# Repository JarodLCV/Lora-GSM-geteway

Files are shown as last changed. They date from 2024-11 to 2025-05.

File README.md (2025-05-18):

# **Passerelle LoRa-GSM**  

Un projet combinant des connaissances en électronique et en programmation pour créer un pont entre le GSM et le LoRa.



----

**Table de matières**
- [**Passerelle LoRa-GSM**](#passerelle-lora-gsm)
  - [ℹ️ **Contexte du projet**](#ℹ️-contexte-du-projet)
  - [🗂️ Dossiers](#️-dossiers)
  - [**Réalisation du projet**](#réalisation-du-projet)
    - [**Définitions :**](#définitions-)
  - [Comment continuer le projet](#comment-continuer-le-projet)
  - [Explication du code](#explication-du-code)

----

## ℹ️ **Contexte du projet**

Il s'agit d'un projet du cours de Projet d'Électronique, encadré par Monsieur Christian Peter (<Christian.PETER@univ-cotedazur.fr>), dans le cadre du cursus d'Ingénierie Électronique et Informatique Industrielle de la Polytech de Sophia Antipolis.  
Ce projet consiste à concevoir une ruche connectée, incluant la collecte de données, la transmission de ces données à distance, l’élimination des parasites par laser, etc.  
Cette partie du projet concerne la communication à distance des données et est réalisée par le groupe composé de:
**Guilherme VENTAPANE RODRIGUES** <guilherme@ventapane.eu>
et
**Jarod LECOEUVRE** <jarod.lecoeuvre@etu.univ-cotedazur.fr>

## 🗂️ Dossiers

- 📁 **Compte-rendu** : Les étapes d'avancement du projet et les tâches que chaque membre du groupe avait effectuées.

- 📁 **Partie_Electronique** : Fichiers liés à la partie électronique du projet, tels que le schéma de la carte, la documentation des composants, etc.
  - 📁 **BOM** : Bill of Material de notre projet. La liste des composants nécessaires avec leurs valeurs, pour être placés sur le PCB.
  - 📁 **Documentation_composants** : Fichiers de documentation pour certains composants utilisés dans le projet.
  - 📁 **Eagle_Components** : Composants supplémentaires pour le logiciel EAGLE, qui n'étaient pas présents par défaut et que nous avons dû télécharger pour compléter notre projet.
  - 📁 **Eagle_Schemas** : Schémas que nous avons utilisés pour notre projet, réalisés avec le logiciel EAGLE d'Autodesk.
  - 📁 **Nano to micro simcard adapter 3d** : Un adaptateur de carte SIM vers micro SIM que nous avons imprimé en 3D pour notre projet.
  - 📁 **Anciens_Schemas** : Fichiers de schémas du groupe de l'année dernière.

- 📁 **Partie_Informatique** : Le dossier où se trouve le code qui tourne sur la carte.
  - 📁 **code_groupe_annee_derniere** : Code du projet du groupe de l'année dernière.
  - 📁 **src** : Les fichiers sources de notre projet, où se trouve le fichier main.ino, le fichier principal de notre projet.

## **Réalisation du projet**  

Pour assurer la communication des données sur de longues distances, une passerelle entre LoRa et GSM sera utilisée.  
Cette passerelle sera réalisée à partir d'un circuit imprimé conçu par nous, ainsi que d'un code exécuté sur un **ESP32** connecté à un **SIM7000G**.

Nous nous basons sur le projet de la promotion précédente, réalisé par **Oumar Sadjo Barry & Mor Dieng** / [oumarsadjo / RucherLoRa](https://github.com/oumarsadjo/RucherLoRa)  
<oumar-sadjo.barry@etu.univ-cotedazur.fr> & <mor.dieng@etu.univ-cotedazur.fr>

### **Définitions :**  

**GSM (Global System for Mobile Communications) :**  
C'est un standard de communication mobile utilisé pour la téléphonie cellulaire et la transmission de données. Il permet l’envoi de messages SMS, les appels et la connexion à Internet via **GPRS/EDGE/3G/4G**. Le GSM est largement utilisé pour les dispositifs IoT nécessitant une connectivité dans des environnements sans Wi-Fi.  

**LoRa (Long Range) :**  
C'est une technologie de communication sans fil à longue portée et à faible consommation d'énergie, utilisée pour connecter des dispositifs IoT aux réseaux LPWAN (**Low Power Wide Area Network**). LoRa permet de transmettre de petits paquets de données sur de longues distances (jusqu'à 15 km en zones rurales) avec une consommation d’énergie minimale.  

**ESP32 :**  
C'est un microcontrôleur développé par Espressif, intégrant **Wi-Fi et Bluetooth**, ainsi que plusieurs broches **GPIO** pour les capteurs et modules externes. Il est largement utilisé dans les projets IoT grâce à sa connectivité, sa puissance et son faible coût.  

**SIM7000 :**  
C'est un module de communication **GSM/GPRS/NB-IoT/LTE Cat-M1** développé par Simcom. Il permet aux dispositifs IoT d'envoyer et de recevoir des données via les réseaux mobiles, en prenant en charge les connexions **basse consommation**, idéales pour les capteurs distants et les applications de surveillance.  



## Comment continuer le projet

Il reste encore à :
- [ ] Finaliser le débogage de la carte pour établir une communication stable entre les composants ;
- [ ] Intégrer la partie LoRa ;
- [ ] Optimiser la consommation énergétique de la passerelle, pour un usage autonome sur batterie.

## Explication du code

La bibliothèque utilise la communication série (UART) pour envoyer des commandes AT au module GSM. En interne, elle structure ces commandes de façon organisée, permettant au développeur de simplement appeler des fonctions comme modem.gprsConnect() ou modem.sendSMS(), au lieu d’écrire manuellement des lignes du type `AT+CGDCONT=1`,"IP","internet".

TinyGSM est également optimisée pour fonctionner sur des cartes à faible mémoire (d’où le “Tiny” dans son nom), ce qui la rend efficace même sur des microcontrôleurs limités comme l’Arduino Uno.

Analyse du code et explication des parties principales

Le code de notre projet est organisé en plusieurs étapes : configuration, initialisation du modem, choix des modes réseau, test de la connexion GPRS, et envoi de SMS. Voici un résumé des parties essentielles :

Définition du modem et configuration initiale
Au début du code, on définit le type de modem utilisé :

``` CPP
#define TINY_GSM_MODEM_SIM7000
#define TINY_GSM_RX_BUFFER 1024
#define SerialAT Serial1
```

Ces lignes informent la bibliothèque qu’on utilise un SIM7000. On augmente aussi la taille du buffer de réception à 1024 octets, ce qui est utile pour traiter des réponses longues du modem.

Il y a aussi l’option suivante :

``` CPP
#define DUMP_AT_COMMANDS
```

Cela permet d’afficher toutes les commandes AT envoyées et les réponses reçues. C’est très utile pour déboguer si quelque chose ne fonctionne pas comme prévu.

Paramètres pour le réseau mobile

``` CPP
const char apn[]  = "sl2sfr";
const char gprsUser[] = "";
const char gprsPass[] = "";
```

Ici, on entre les informations nécessaires pour se connecter au réseau mobile. L’APN dépend de l’opérateur utilisé. Dans notre cas, c’est “sl2sfr” car nous utilisons un SIM de SFR.

Initialisation du modem

Dans la fonction setup(), on initialise la communication série avec le modem :

``` CPP
SerialAT.begin(UART_BAUD, SERIAL_8N1, PIN_RX, PIN_TX);
```

Ensuite, on redémarre le modem avec `modem.restart()` et on vérifie si tout s’est bien passé.

On récupère aussi quelques infos utiles :

``` CPP
String name = modem.getModemName();
String modemInfo = modem.getModemInfo();
```

Cela permet d’afficher le nom du modem et quelques infos techniques pour s’assurer que le module est bien reconnu.

Configuration du mode réseau

Dans la `loop()`, on configure le mode de fonctionnement du modem :

``` CPP
modem.sendAT("+CFUN=0"); // désactive le modem temporairement
modem.setNetworkMode(2); // mode automatique
modem.setPreferredMode(1); // priorité au mode CAT-M
modem.sendAT("+CFUN=1"); // réactive le modem
```

Ces commandes AT permettent de choisir comment le modem va chercher le réseau (LTE, GSM, NB-IoT, etc.).

Connexion GPRS

Une fois le modem prêt, on tente de se connecter au réseau mobile :

``` CPP
modem.gprsConnect(apn, gprsUser, gprsPass);
```

Après la connexion, on peut vérifier le signal, l’opérateur, l’IMEI, l’adresse IP locale, etc.

Envoi de SMS

À la fin du code, il y a une partie pour tester l’envoi de SMS :

``` CPP
modem.sendSMS(SMS_TARGET, String("Hello from ") + imei);
```

C’est un test simple qui envoie un message contenant l’IMEI du module à un numéro prédéfini.

Mise hors tension et sommeil profond

Enfin, on met le modem hors tension et on fait entrer l’ESP32 en mode sommeil profond pour économiser l’énergie :

``` CPP
modem.poweroff();
esp_deep_sleep_start();
```

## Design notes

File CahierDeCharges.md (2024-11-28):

# Gateway LORA-GSM
- Guilherme VENTAPANE RODRIGUES
- Jarod LECOEUVRE

Voir [Projet de l'année dernière](https://github.com/oumarsadjo/RucherLoRa) par Mor et Oumar.

## Objectif Principal du projet :
- Faire une passarèle entre LoRa et GSM.

### Application CAO choisie
Autodesk EAGLE et Autodesk Fusion

## Définitions:
**LoRa** = Communication en longe distance et faible consommation énergetique.
**GSM (Global System for Mobile Communications) : *** = GSM est une norme de téléphonie mobile largement utilisée pour la communication cellulaire. Elle permet la transmission de voix et de données sur des réseaux mobiles à l’échelle mondiale, facilitant la connectivité mobile entre les appareils et les utilisateurs.

## État au démarrage :
- Repris le projet Mor et Oumar.
- Documentation, dessin du circuit, disponibles sur le repositoire GitHub du projet.
- Carte déjà imprimmée.
- Interface pour connecter via USB réalisée.

### Problèmes constatés :
- Court circuit à l'entrée du circuit.
- Tous les composants connectés à la masse en court circuit.
- Des LEDs alimentés entre masse et masse.
- Utilisation des NMOS à la place des PMOS.
- LEDs liés entre masse et rien.

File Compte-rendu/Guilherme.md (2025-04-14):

<h1 align="center" color="#009900">📝 Compte Rendu | Guilherme VENTAPANE RODRIGUES</h1>
<h2>Sommaire:</h2>

- [Partie 1 : **Avant** la **présentation 1**](#partie-1--avant-la-présentation-1)
  - [Lundi 23 Septembre 2024](#lundi-23-septembre-2024)
  - [Mardi 12 Novembre 2024](#mardi-12-novembre-2024)
    - [Liste de composants :](#liste-de-composants-)
  - [Du 18 au 20 Novembre 2024 (à la maison)](#du-18-au-20-novembre-2024-à-la-maison)
  - [Lundi 25 Novembre 2024](#lundi-25-novembre-2024)
  - [Mardi 26 Novembre 2024](#mardi-26-novembre-2024)
  - [Jeudi 5 Décembre 2024 (à la maison)](#jeudi-5-décembre-2024-à-la-maison)
  - [Lundi 9 Décembre 2024](#lundi-9-décembre-2024)
  - [Mardi 7 Janvier 2025](#mardi-7-janvier-2025)
  - [Samedi 18 Janvier 2025 (à la maison)](#samedi-18-janvier-2025-à-la-maison)
  - [Dimanche 2 Février 2025 (à la maison)](#dimanche-2-février-2025-à-la-maison)
  - [Lundi 3 Février 2025](#lundi-3-février-2025)
  - [Lundi 10 Février 2025](#lundi-10-février-2025)
- [Partie 2 : **Après** la **présentation 1**](#partie-2--après-la-présentation-1)
  - [Mardi 25 Février 2025](#mardi-25-février-2025)
  - [Vendredi 28 Février 2025](#vendredi-28-février-2025)
  - [Lundi 10 Mars 2025](#lundi-10-mars-2025)
  - [Mardi 11 Mars 2025](#mardi-11-mars-2025)
  - [Lundi 24 et Mardi 25 Mars](#lundi-24-et-mardi-25-mars)
  - [Lundi 7 Avril](#lundi-7-avril)
  - [Vendredi 11 Avril](#vendredi-11-avril)
    - [**Partie 1 : Tester sur la HELTEC ESP32**](#partie-1--tester-sur-la-heltec-esp32)
    - [**Partie 2 : Tester sur notre prototype**](#partie-2--tester-sur-notre-prototype)

# Partie 1 : **Avant** la **présentation 1**

## Lundi 23 Septembre 2024

- Essai d'adapter Altium pour l'installer sur Mac.
- Problème d'installation, Jarod va l'installer sur Windows.
- Découverte d'un problème de liaison entre VCC et la masse.

## Mardi 12 Novembre 2024

- Nous avons vu avec Monsieur Peter que le projet de l'année dernière avait plusieurs autres problèmes donc on devra tout réfaire.
- Court-circuit à l'entrée du circuit.
  
  
- Tous les composants sont liés à la masse.
  
  
- LEDs alimentées entre masse et masse.
  
  
- Utilisation des NMOS à la place des PMOS.
  
  
- LEDs liées entre la masse et rien.
  
  

- Recherche de la documentation des composants principaux du circuit. Une partie était disponible sur GitHub.
- Commencé à regarder comment importer des nouveaux composants dans Fusion.
- Écriture du brouillon du cahier des charges.

### Liste de composants :

- SimCom SIM7000G : [https://www.manualslib.com/manual/1498555/Simcom-Sim7000g.html?page=20#manual](https://www.manualslib.com/manual/1498555/Simcom-Sim7000g.html?page=20#manual)
- ESP32 Wrover B.
- Antenne GSM.
- ...

## Du 18 au 20 Novembre 2024 (à la maison)

- Créé un compte étudiant Autodesk.
- Téléchargé le logiciel Autodesk Fusion.
- Travaillé à la maison pour comprendre comment utiliser le logiciel.
- Pris des cours d'électronique en ligne pour Fusion.
- Dessiné et simulé des circuits simples pour m'entraîner.

## Lundi 25 Novembre 2024

- Passé le cahier des charges de la version lablette à la version Markdown, sur GitHub.
- Ouverture des fichiers de dessin dans Eagle.
- Ajout de la documentation et des schémas sur GitHub.
- Recherche de la documentation des composants :
  - TXB0108PWR : [https://www.ti.com/lit/ds/symlink/txb0108.pdf](https://www.ti.com/lit/ds/symlink/txb0108.pdf)
  - Cherché le symbol et le footprint des composants pour pouvoir les ajouter dans Eagle.
  - Ajouté les composants dans Eagle.
  - Commencé à reconstruire le circuit.

## Mardi 26 Novembre 2024

- Revenu au schéma précédent car il avait déjà les composants nécessaires.
- Remplacé une entrée par 3V.
- Modifié la liste de composants.

- Problèmes trouvés et corrigés avec des composants :
  - R9 : Rien de branché.
  - JP2 lié à rien.
  - R20 et R18 liées à rien -> Branché à Q7, C5, D3 et la masse.
  - Q8 : l'une des pattes pas branchée !!! (toujours pas réglé).
  - R10 : Une seule patte branchée.
  - LED R1 liée que dans une seule patte.

## Jeudi 5 Décembre 2024 (à la maison)

- Continué à faire le routage du circuit.
- TODO : Vérifier si j'ai choisi la bonne taille pour les pistes.
- Appris comment faire le routage de la partie bottom avec : [https://www.autodesk.com/products/fusion-360/blog/routing-autorouting-pcb-layout-basics-2/](https://www.autodesk.com/products/fusion-360/blog/routing-autorouting-pcb-layout-basics-2/)
- Beaucoup avancé le routage top et bottom.

## Lundi 9 Décembre 2024

- Modifié les miles du routage.
- Terminé le routage.
- Regardé le code de la carte avec Jarod pour essayer de faire communiquer la carte avec le PC, puis envoyer un message SMS.

## Mardi 7 Janvier 2025

- J'ai regardé avec Jarod pour essayer de tester la carte avec le code. Nous n'avons toujours pas réussi.
- J'ai trouvé et installé une autre bibliothèque pour le GSM appelée TinyGSM.
- J'ai vu avec le professeur qu'il restait encore plusieurs soucis sur le schéma EAGLE :
  1. V+ branché à ground
     1. Solution : Les remplacer par un nouveau V+ trouvé dans sources1.
  2. Pistes qui passent par la Keepout Zone du SIM7000
     1. Solution : Enlever les pistes ou les passer par la face bottom.
  3. Condensateurs de couplage trop éloignés de la SIM7000
     1. Solution : Déplacer la SIM7000 vers le bas pour avoir la place.
- J'ai enlevé toutes les pistes pour pouvoir déplacer les composants d'une façon plus optimisée.

## Samedi 18 Janvier 2025 (à la maison)

- Continué à faire le cablage

## Dimanche 2 Février 2025 (à la maison)

- Continué à faire le cablage
- Remarqué qu'il manquait beaucoup de cablage sur le schéma du TXT0108PWR, reglé ça:
  1. LTE_RXD
  2. LTE_TXD
  3. LTE_RI
  4. LTE_DRT
  5. LTE_SDA
  6. LTE_SCL
  
  Corrigé:
  

  Connexions maintenat disponibles:
  
  
- Corrigé la taille des images dans le compte rendu.
- Respecté la zone de Keepout du SIM7000.
- Écriture de la documentation dans Readme.md.

## Lundi 3 Février 2025

- Continué à faire le routage puis passé à Jarod, pour que je puisse regarder le code.
- Fait plusieurs essais avec le code et des nouvelles libraries.
- Pas encore réussi.
- J'amène la carte à la maison pour vérifier le cablage et continuer à faire des essais.


## Lundi 10 Février 2025

Présentation du projet.  
Points d'amélioration :  
- Utiliser Gantt pour la gestion du projet.  
- Utiliser un peu plus d'images.  
- Améliorer ma fluidité en français  

# Partie 2 : **Après** la **présentation 1**  

## Mardi 25 Février 2025  

🚩 **Événement** : Arrivée du circuit imprimé.  
  

Lors de ce dernier cours, Jarod a réalisé des tests sur son PC avec l'ESP32.  
Pendant ce temps, j'ai décidé de tester chaque carte SIM7000G sur mon ordinateur via la communication par port série, en utilisant une application appelée Serial Tools.  


Je n'ai obtenu aucun succès avec aucun des circuits.  

Ensuite, nous avons échangé les rôles : j'ai pris en charge la partie ESP32 pendant que Jarod testait les cartes SIM7000G.  
Après plusieurs essais, j'ai imaginé que le problème pouvait venir de la manière dont les câbles étaient connectés à l'ESP32.  

- J'ai consulté la documentation de l'ESP32 Heltec LoRa V3.  
- J'ai consulté la documentation du SIM7000G.  
- J'ai entièrement refait le câblage.  
- J'ai découvert que l'erreur venait du choix des terminaux du GPIO.


Comme on peut le voir sur l'image, l'ESP32 possède deux rangées numérotées. Pour moi, il ne semblait pas logique qu'un même numéro représente les deux côtés, étant donné qu'ils ne remplissent pas forcément la même fonction. Après vérification avec le professeur, c'était bien le cas.  

Ainsi, voici le circuit refait :  
  

Cette fois, au lieu d'utiliser 16 et 17 pour les sorties GPIO TX et RX, j'ai utilisé 19 et 20, qui sont les sorties correctes du GPIO.  

Cela a fonctionné correctement et nous pouvons maintenant communiquer avec le SIM7000G et progresser avec le projet.  

Cependant, bien que la connexion avec le SIM7000G soit établie, il n'était toujours pas possible de se connecter au réseau GPRS et d'envoyer des messages. J'ai tenté les actions suivantes :  

- Changer l'antenne utilisée pour le LTE.  
- Changer le circuit SIM7000G.  
- Insérer la carte SIM de mon téléphone dans le module.  
- Mettre la carte SIM du SIM7000G dans mon téléphone, où j'ai pu envoyer un message à Jarod.  

Après en avoir discuté avec le professeur, la prochaine étape consistera à essayer avec le code du groupe de l'année dernière.  

## Vendredi 28 Février 2025  

À faire pour ce cours :  

- [x] Continuer à tester les cartes, avec la SIM7000 et le ESP32, avec le code du groupe de l'année dernière.

## Lundi 10 Mars 2025

J'ai testé chacune des cartes pour voir si elles fonctionnent.  
L'une d'elles n'a pas fonctionné et a été remise au professeur.

- J'ai continué à éditer le code, en envoyant diverses commandes AT pour voir le type de message qui apparaissait, comme une manière de déboguer le code.
- Le message NO CARRIER continuait d'apparaître.
- Le professeur a suggéré d'alimenter la carte avec une alimentation externe, car peut-être le problème venait du fait qu'il n'y avait pas assez d'énergie pour permettre au SIM7000 de fonctionner correctement.
- Nous avons réalisé le test et cela a effectivement fonctionné, nous avons commencé à voir des messages différents sur le SIM7000 (sur le port Serial avec Arduino IDE).

## Mardi 11 Mars 2025

- Le professeur a apporté un circuit intégré déjà prêt avec l'intégration entre le SIM7000 et l'ESP32, appelé LilyGO T SIM7000.
- J'ai fait quelques recherches dans la documentation en ligne, mais nous avons décidé qu'il serait préférable que chacun essaie de son côté.
- Ma tâche consistait à tester le code avec l'ancien circuit et Jarod testerait avec le nouveau.
- Pendant un certain temps, j'ai continué à tester notre code sur l'ancien circuit, mais sans beaucoup de succès, jusqu'à ce que je trouve une bonne documentation du LilyGO T SIM7000 qui m'a donné une piste sur ce que je devais faire.

> [!TIP] J'AI RÉUSSI À FAIRE FONCTIONNER LA CARTE ET À ENVOYER UN MESSAGE PAR SMS

J'ai réussi à faire fonctionner ! Grâce au code que j'ai trouvé sur le site  
https://randomnerdtutorials.com/lilygo-t-sim7000g-esp32-lte-gprs-gps/

- J'ai modifié le code selon nos besoins.
- La différence principale est l'utilisation de la bibliothèque TinyGSM.
- L'étape a été validée par le professeur, alors j'ai commencé à placer les composants. Pendant ce temps, Jarod retirait les parties inutiles du code.
- Il faisait des modifications dans le code et l'IDE a cessé d'envoyer le code à la carte.
- J'ai proposé que nous échangions : il continuerait à placer les composants sur le circuit et j'essaierais de résoudre ce nouveau problème sur le code.
- J'ai réussi à résoudre le problème et les circuits envoient, de nouveau, des messages par SMS.

## Lundi 24 et Mardi 25 Mars

- Ces jours-là, nous avons préparé notre propre circuit imprimé.
- Le professeur a appliqué la pâte à souder sur le circuit.
[IMG: Circuit avec la pâte à souder]
- J'ai placé les composants sur la carte.
- Nous avons mis le circuit au four.
- J'ai soudé une partie des composants traversants et Jarod les autres.
[IMG: Circuit avec les composants déjà soudés]
- Nous avons réalisé des tests, mais malheureusement, nous n'arrivions pas à transmettre le code au circuit via l'IDE Arduino.
- Le professeur a suggéré que, comme méthode de débogage pour savoir ce qui n'allait pas avec le circuit, nous devrions placer les composants un par un par groupe de composants.
- Nous avons commencé par l'ESP32, car c'est la partie principale et essentielle de notre circuit.
- Cela devait être fait en appliquant la pâte à souder sur un PCB et, petit à petit, en plaçant les composants, en utilisant un pistolet à air chaud pour faire fondre l'étain.
- **Cela a fonctionné. Nous avons réussi à envoyer un code à notre nouveau PCB, qui, pour l'instant, n'avait que l'ESP32.**

## Lundi 7 Avril

- Nous avons repris les tests sur notre nouveau circuit.
- Au début, cela ne fonctionnait pas, alors j'ai suggéré de remettre le cavalier, et cela a recommencé à fonctionner.
- Jarod a soudé la partie alimentation en utilisant un pistolet à air chaud.

## Vendredi 11 Avril

- Définition des modifications à faire dans le code.
- Nous avons divisé les tâches : je ferais la partie code et lui effectuerait les tests sur la nouvelle carte que nous sommes en train de monter pour déboguer.

### **Partie 1 : Tester sur la HELTEC ESP32**

- Cahier des charges pour les modifications dans le code :
  - Réussir à lire les messages reçus.
  - Envoyer un message.
  - Envoyer une requête REST.

### **Partie 2 : Tester sur notre prototype**

- Jarod a testé le code sur notre circuit et cela a fonctionné. Les messages ont été envoyés et reçus.
- L'étape pour le prochain cours sera de souder le SIM7000 avec les composants nécessaires et de réaliser les tests.
[IMG: Jarod testant le circuit avec le multimètre]

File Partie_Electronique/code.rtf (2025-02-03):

#define TINY_GSM_MODEM_SIM7000

#include <TinyGsmClient.h>

#include <HardwareSerial.h>

HardwareSerial mySerial(2); // UART2 for SIM7000G

// Define TinyGSM modem
TinyGsm modem(mySerial);

void setup() {
// Start USB Serial for debugging
Serial.begin(115200);
delay(10);

// Initialize UART2 for the modem
mySerial.begin(115200, SERIAL_8N1, 16, 17);

Serial.println("Initializing modem...");
modem.sendAT("+CSQ"); // Check signal quality
delay(1000);

// Print response to Serial Monitor
while (mySerial.available()) {
Serial.write(mySerial.read());
}

if (!modem.restart()) {
Serial.println("Failed to initialize modem!");
while (true);
}

Serial.println("Modem initialized!");

// Wait for network connection
if (!modem.waitForNetwork(30000)) {
Serial.println("Failed to connect to network!");
while (true);
}
Serial.println("Network connected!");

// Send SMS
String recipient = "+1234567890"; // Replace with recipient's number
String message = "Hello from TinyGSM!";
if (modem.sendSMS(recipient, message)) {
Serial.println("SMS sent successfully!");
} else {
Serial.println("Failed to send SMS!");
}
}

void loop() {
// Nothing to do in the loop
}

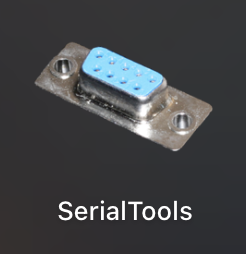
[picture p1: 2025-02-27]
Compte-rendu/image.png

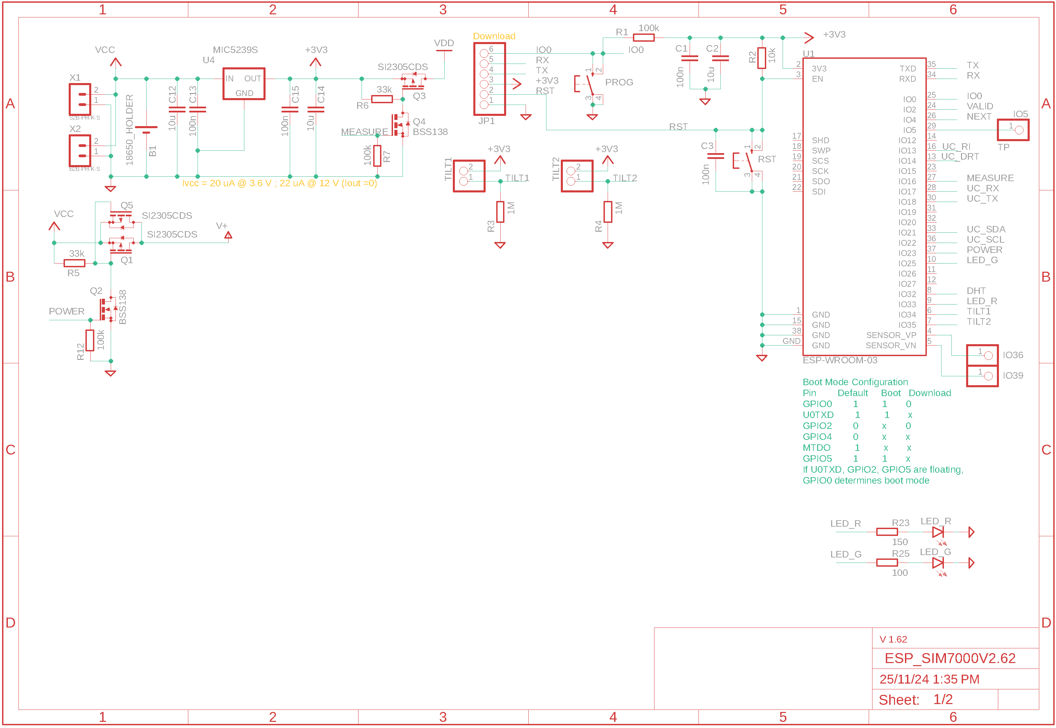
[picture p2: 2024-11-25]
Schemas/schema_pour_esp.png

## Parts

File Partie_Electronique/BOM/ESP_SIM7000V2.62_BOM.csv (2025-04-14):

Part | Value | Device | Package | Description | AVAILABILITY | CHECK_PRICES | DESCRIPTION | DIGIKEY_PART_NUMBER | MF | MP | MPN | OC_FARNELL | OC_NEWARK | PACKAGE | POPULARITY | PRICE | PURCHASE-URL | RS_COMPONENTS_1674235_PURCHASE_URL | RS_COMPONENTS_7099038P_PURCHASE_URL | RS_COMPONENTS_7099038_PURCHASE_URL | RS_COMPONENTS_7867096P_PURCHASE_URL | RS_COMPONENTS_7867096_PURCHASE_URL | RS_COMPONENTS_9215119_PURCHASE_URL | SNAPEDA_LINK | SPICEMODEL | SPICEPREFIX
B1 | 18650_HOLDER | 18650_HOLDER | 18650 | 18650 holder
C1 | 100n | CC1206 | C1206 | CAPACITOR, European symbol |  |  |  |  |  |  |  |  |  |  |  |  |  |  |  |  |  |  |  |  | NONE | C
C2 | 10u | CC1210 | C1210 | CAPACITOR, European symbol |  |  |  |  |  |  |  |  |  |  |  |  |  |  |  |  |  |  |  |  | NONE | C
C3 | 100n | CC1206 | C1206 | CAPACITOR, European symbol |  |  |  |  |  |  |  |  |  |  |  |  |  |  |  |  |  |  |  |  | NONE | C
C4 | 33pF | C-EUC0805 | C0805 | CAPACITOR, European symbol |  |  |  |  |  |  |  |  |  |  | 88 |  |  |  |  |  |  |  |  |  |  | C
C5 | 100nF | C-EUC0805 | C0805 | CAPACITOR, European symbol |  |  |  |  |  |  |  |  |  |  | 88 |  |  |  |  |  |  |  |  |  |  | C
C6 | 100nF | C-EUC0805 | C0805 | CAPACITOR, European symbol |  |  |  |  |  |  |  |  |  |  | 88 |  |  |  |  |  |  |  |  |  |  | C
C7 | 0.22uF | C-EUC0805 | C0805 | CAPACITOR, European symbol |  |  |  |  |  |  |  |  |  |  | 88 |  |  |  |  |  |  |  |  |  |  | C
C8 | 1uF | C-EUC0805 | C0805 | CAPACITOR, European symbol |  |  |  |  |  |  |  |  |  |  | 88 |  |  |  |  |  |  |  |  |  |  | C
C11 | 0.1uF | C-EUC0805 | C0805 | CAPACITOR, European symbol |  |  |  |  |  |  |  |  |  |  | 88 |  |  |  |  |  |  |  |  |  |  | C
C12 | 10u | CC1210 | C1210 | CAPACITOR, European symbol |  |  |  |  |  |  |  |  |  |  |  |  |  |  |  |  |  |  |  |  | NONE | C
C13 | 100n | CC1206 | C1206 | CAPACITOR, European symbol |  |  |  |  |  |  |  |  |  |  |  |  |  |  |  |  |  |  |  |  | NONE | C
C14 | 10u | CC1210 | C1210 | CAPACITOR, European symbol |  |  |  |  |  |  |  |  |  |  |  |  |  |  |  |  |  |  |  |  | NONE | C
C15 | 100n | CC1206 | C1206 | CAPACITOR, European symbol |  |  |  |  |  |  |  |  |  |  |  |  |  |  |  |  |  |  |  |  | NONE | C
C16 | 100uF | C-EUC0805 | C0805 | CAPACITOR, European symbol |  |  |  |  |  |  |  |  |  |  | 88 |  |  |  |  |  |  |  |  |  |  | C
C17 | 100uF | C-EUC0805 | C0805 | CAPACITOR, European symbol |  |  |  |  |  |  |  |  |  |  | 88 |  |  |  |  |  |  |  |  |  |  | C
C18 | 100nF | C-EUC0805 | C0805 | CAPACITOR, European symbol |  |  |  |  |  |  |  |  |  |  | 88 |  |  |  |  |  |  |  |  |  |  | C
C20 | 0.1uF | CC1210 | C1210 | CAPACITOR, European symbol |  |  |  |  |  |  |  |  |  |  |  |  |  |  |  |  |  |  |  |  | NONE | C
C21 | 0.1uF | CC1210 | C1210 | CAPACITOR, European symbol |  |  |  |  |  |  |  |  |  |  |  |  |  |  |  |  |  |  |  |  | NONE | C
D1 | MSQA6V1W5T2G | MSQA6V1W5T2G | SC88A | ESD Protection Diode Array Check availability | In Stock | https://www.snapeda.com/parts/MSQA6V1W5T2G/Onsemi/view-part/?ref=eda | Clamp Ipp Tvs Diode Surface Mount SC-88A (SC-70-5/SOT-353) |  | onsemi | MSQA6V1W5T2G |  |  |  | SC-88A-5 ON Semiconductor |  | None | https://www.snapeda.com/api/url_track_click_mouser/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 |  |  |  |  |  |  | https://www.snapeda.com/parts/MSQA6V1W5T2G/Onsemi/view-part/?ref=snap
D2 | PESD5V0X1UB | PESD5V0X1UB | SOD523 | Ultra low capacitance unidirectional ElectroStatic Discharge (ESD) protection diode in a | In Stock | https://www.snapeda.com/parts/PESD5V0X1UB/Nexperia/view-part/?ref=eda | 8V (Typ) Clamp 1.5A (8/20µs) Ipp Tvs Diode Surface Mount SOD-523 |  | Nexperia USA | PESD5V0X1UB |  |  |  | SOD-523 NXP Semiconductors |  | None |  |  |  |  |  |  |  | https://www.snapeda.com/parts/PESD5V0X1UB/Nexperia/view-part/?ref=snap
D3 | PESD5V0X1UB | PESD5V0X1UB | SOD523 | Ultra low capacitance unidirectional ElectroStatic Discharge (ESD) protection diode in a | In Stock | https://www.snapeda.com/parts/PESD5V0X1UB/Nexperia/view-part/?ref=eda | 8V (Typ) Clamp 1.5A (8/20µs) Ipp Tvs Diode Surface Mount SOD-523 |  | Nexperia USA | PESD5V0X1UB |  |  |  | SOD-523 NXP Semiconductors |  | None |  |  |  |  |  |  |  | https://www.snapeda.com/parts/PESD5V0X1UB/Nexperia/view-part/?ref=snap
IO5 | TP | PINHD-1X1 | 1X01 | PIN HEADER |  |  |  |  |  |  |  |  |  |  | 64
IO36 |  | PINHD-1X1 | 1X01 | PIN HEADER |  |  |  |  |  |  |  |  |  |  | 64
IO39 |  | PINHD-1X1 | 1X01 | PIN HEADER |  |  |  |  |  |  |  |  |  |  | 64
J1 | U.FL-R-SMT(01) | U.FL-R-SMT(01) | HRS_U.FL-R-SMT(01) | U.FL Series 6 Ghz 50 Ohm Ultra-small SMT Coaxial Cable Receptacle Check availability | In Stock | https://www.snapeda.com/parts/U.FL-R-SMT(01)/Hirose+Electric+Co+Ltd/view-part/?ref=eda | U.FL (UMCC) Connector Receptacle, Male Pin 50Ohm Surface Mount Solder. RF Connectors / Coaxial Connectors |  | Hirose | U.FL-R-SMT(01) |  |  |  | None |  | None | https://www.snapeda.com/api/url_track_click_mouser/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 |  |  |  |  |  |  | https://www.snapeda.com/parts/U.FL-R-SMT(01)/Hirose+Electric+Co+Ltd/view-part/?ref=snap
J2 | U.FL-R-SMT(01) | U.FL-R-SMT(01) | HRS_U.FL-R-SMT(01) | U.FL Series 6 Ghz 50 Ohm Ultra-small SMT Coaxial Cable Receptacle Check availability | In Stock | https://www.snapeda.com/parts/U.FL-R-SMT(01)/Hirose+Electric+Co+Ltd/view-part/?ref=eda | U.FL (UMCC) Connector Receptacle, Male Pin 50Ohm Surface Mount Solder. RF Connectors / Coaxial Connectors |  | Hirose | U.FL-R-SMT(01) |  |  |  | None |  | None | https://www.snapeda.com/api/url_track_click_mouser/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 |  |  |  |  |  |  | https://www.snapeda.com/parts/U.FL-R-SMT(01)/Hirose+Electric+Co+Ltd/view-part/?ref=snap
J3 | 78646-3001 | 78646-3001 | MOLEX_78646-3001 | Conn Micro SIM Card SKT 6 POS 2.54mm Solder RA SMD 0.5A/Contact Embossed T/R Check availability | In Stock | https://www.snapeda.com/parts/78646-3001/Molex/view-part/?ref=eda | Horizontal Surface Mount Micro SIM Card Connector, with Push In Termination | Molex Incorporated 78646-3001 |  | Molex | 78646-3001 |  |  |  | None |  | None | https://www.snapeda.com/api/url_track_click_mouser/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 sim |  |  |  |  |  |  | https://www.snapeda.com/parts/78646-3001/Molex/view-part/?ref=snap
JP1 |  | PINHD-1X6 | 1X06 | PIN HEADER |  |  |  |  |  |  |  |  |  |  | 79
JP2 |  | PINHD-1X1 | 1X01 | PIN HEADER |  |  |  |  |  |  |  |  |  |  | 64
JP3 |  | PINHD-1X1 | 1X01 | PIN HEADER |  |  |  |  |  |  |  |  |  |  | 64
L1 | 27nH | LQM21PN1R0NGRD | INDC2012X100N | LQM21PN 1uH 950mA 30% MLT |  | https://www.snapeda.com/parts/LQM21PN1R0NGRD/Murata+Electronics+North+America/view-part/?ref=eda | Inductor with Inductance: 1uH Tol. +/-30%, Package: 0805 (2012) |  | Murata | LQM21PN1R0NGRD |  |  |  | 2012 Murata |  |  | https://www.snapeda.com/api/url_track_click_mouser/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 0805 | https://www.snapeda.com/api/url_track_click/https%253A//uk.rs-online.com/web/p/surface-mount-inductors/1674235//%253Futm_campaign%253Dbuynow%2526utm_medium%25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 0805 |  |  | https://www.snapeda.com/api/url_track_click/https%253A//uk.rs-online.com/web/p/surface-mount-inductors/7867096p//%253Futm_campaign%253Dbuynow%2526utm_medium%2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 0805 | https://www.snapeda.com/api/url_track_click/https%253A//uk.rs-online.com/web/p/surface-mount-inductors/7867096//%253Futm_campaign%253Dbuynow%2526utm_medium%25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 0805 |  | https://www.snapeda.com/parts/LQM21PN1R0NGRD/Murata+Electronics+North+America/view-part/?ref=snap
LED_G |  | LEDSMT1206 | 1206 | LED |  |  |  |  |  |  |  |  |  |  | 20
LED_R |  | LEDSMT1206 | 1206 | LED |  |  |  |  |  |  |  |  |  |  | 20
LED_R1 | Bleue | LEDSMT1206 | 1206 | LED |  |  |  |  |  |  |  |  |  |  | 20
LED_R2 | Bleue | LEDSMT1206 | 1206 | LED |  |  |  |  |  |  |  |  |  |  | 20
PROG |  | 10-XX | B3F-10XX | OMRON SWITCH |  |  |  |  |  |  | B3F-1000 | 176432 | 36M3542 |  | 72
Q1 | SI2305CDS | SI2305CDS | SOT23 | P-CHANNEL MOS FET
Q2 | BSS138 | BSS131 | SOT23 | N-CHANNEL MOS FET
Q3 | SI2305CDS | SI2305CDS | SOT23 | P-CHANNEL MOS FET
Q4 | BSS138 | BSS131 | SOT23 | N-CHANNEL MOS FET
Q5 | SI2305CDS | SI2305CDS | SOT23 | P-CHANNEL MOS FET
Q6 | BSS138 | BSS131 | SOT23 | N-CHANNEL MOS FET
Q7 | BSS138 | BSS131 | SOT23 | N-CHANNEL MOS FET
Q8 | BSS138 | BSS131 | SOT23 | N-CHANNEL MOS FET
Q9 | BSS138 | BSS131 | SOT23 | N-CHANNEL MOS FET
R1 | 100k | RR1206 | R1206 | RESISTOR, European symbol |  |  |  |  |  |  |  |  |  |  |  |  |  |  |  |  |  |  |  |  | NONE | R
R2 | 10k | RR1206 | R1206 | RESISTOR, European symbol |  |  |  |  |  |  |  |  |  |  |  |  |  |  |  |  |  |  |  |  | NONE | R
R3 | 1M | RR1206 | R1206 | RESISTOR, European symbol |  |  |  |  |  |  |  |  |  |  |  |  |  |  |  |  |  |  |  |  | NONE | R
R4 | 1M | RR1206 | R1206 | RESISTOR, European symbol |  |  |  |  |  |  |  |  |  |  |  |  |  |  |  |  |  |  |  |  | NONE | R
R5 | 33k | RR1206 | R1206 | RESISTOR, European symbol |  |  |  |  |  |  |  |  |  |  |  |  |  |  |  |  |  |  |  |  | NONE | R
R6 | 33k | RR1206 | R1206 | RESISTOR, European symbol |  |  |  |  |  |  |  |  |  |  |  |  |  |  |  |  |  |  |  |  | NONE | R
R7 | 100k | RR1206 | R1206 | RESISTOR, European symbol |  |  |  |  |  |  |  |  |  |  |  |  |  |  |  |  |  |  |  |  | NONE | R
R8 | 470 | RR1206 | R1206 | RESISTOR, European symbol |  |  |  |  |  |  |  |  |  |  |  |  |  |  |  |  |  |  |  |  | NONE | R
R9 | 33k | RR1206 | R1206 | RESISTOR, European symbol |  |  |  |  |  |  |  |  |  |  |  |  |  |  |  |  |  |  |  |  | NONE | R
R10 | 33k | RR1206 | R1206 | RESISTOR, European symbol |  |  |  |  |  |  |  |  |  |  |  |  |  |  |  |  |  |  |  |  | NONE | R
R11 | 470 | RR1206 | R1206 | RESISTOR, European symbol |  |  |  |  |  |  |  |  |  |  |  |  |  |  |  |  |  |  |  |  | NONE | R
R12 | 100k | RR1206 | R1206 | RESISTOR, European symbol |  |  |  |  |  |  |  |  |  |  |  |  |  |  |  |  |  |  |  |  | NONE | R
R13 | 10 | RR1206 | R1206 | RESISTOR, European symbol |  |  |  |  |  |  |  |  |  |  |  |  |  |  |  |  |  |  |  |  | NONE | R
R14 | NC | RR1206 | R1206 | RESISTOR, European symbol |  |  |  |  |  |  |  |  |  |  |  |  |  |  |  |  |  |  |  |  | NONE | R
R15 | 2.2k | RR1206 | R1206 | RESISTOR, European symbol |  |  |  |  |  |  |  |  |  |  |  |  |  |  |  |  |  |  |  |  | NONE | R
R16 | NC | RR1206 | R1206 | RESISTOR, European symbol |  |  |  |  |  |  |  |  |  |  |  |  |  |  |  |  |  |  |  |  | NONE | R
R17 | 2.2k | RR1206 | R1206 | RESISTOR, European symbol |  |  |  |  |  |  |  |  |  |  |  |  |  |  |  |  |  |  |  |  | NONE | R
R18 | NC | RR1206 | R1206 | RESISTOR, European symbol |  |  |  |  |  |  |  |  |  |  |  |  |  |  |  |  |  |  |  |  | NONE | R
R20 | NC | RR1206 | R1206 | RESISTOR, European symbol |  |  |  |  |  |  |  |  |  |  |  |  |  |  |  |  |  |  |  |  | NONE | R
R22 | 10k | RR1206 | R1206 | RESISTOR, European symbol |  |  |  |  |  |  |  |  |  |  |  |  |  |  |  |  |  |  |  |  | NONE | R
R23 | 150 | RR1206 | R1206 | RESISTOR, European symbol |  |  |  |  |  |  |  |  |  |  |  |  |  |  |  |  |  |  |  |  | NONE | R
R25 | 100 | RR1206 | R1206 | RESISTOR, European symbol |  |  |  |  |  |  |  |  |  |  |  |  |  |  |  |  |  |  |  |  | NONE | R
RST |  | 10-XX | B3F-10XX | OMRON SWITCH |  |  |  |  |  |  | B3F-1000 | 176432 | 36M3542 |  | 72
TILT1 |  | PINHD-1X2 | 1X02 | PIN HEADER |  |  |  |  |  |  |  |  |  |  | 98
TILT2 |  | PINHD-1X2 | 1X02 | PIN HEADER |  |  |  |  |  |  |  |  |  |  | 98
U$1 | SIM7000G | SIM7000G | SIM7000G |  |  | https://www.snapeda.com/parts/SIM7000G/SIMCom/view-part/?ref=eda | 802.15.4 Cat-M, Cat-NB, EDGE, GPRS, LPWA Transceiver Module 850MHz, 900MHz, 1.8GHz, 1.9GHz Antenna Not Included Surface Mount |  | SIMCom Wireless Solutions Limited | SIM7000G |  |  |  | None |  |  | https://www.snapeda.com/api/url_track_click_mouser/?unipart_id=12130268&manufacturer=SIMCom Wireless Solutions Limited&part_name=SIM7000G&search_term=sim7000g |  |  |  |  |  |  | https://www.snapeda.com/parts/SIM7000G/SIMCom/view-part/?ref=snap
U1 | ESP-WROOM-03 | ESP-WROOM-03 | ESP-WROOM-03 |  |  |  |  |  |  |  |  | unknown
U2 | TXB0108PWR | TXB0108PWR | SOP65P640X120-20N | 8-Bit Bidirectional Voltage-Level Shifter with Auto Direction Sensing and +/-15-kV ESD Protect 20-TSSOP -40 to 85 Check availability |  | https://www.snapeda.com/parts/TXB0108PWR/Texas+Instruments/view-part/?ref=eda | 8-Bit Bidirectional Voltage-Level Shifter with Auto Direction Sensing and +/-15-kV ESD Protect |  | Texas Instruments | TXB0108PWR |  |  |  | TSSOP-20 Texas Instruments |  |  | https://www.snapeda.com/api/url_track_click_mouser/?unipart_id=45111&manufacturer=Texas Instruments&part_name=TXB0108PWR&search_term=txb0108 |  | https://www.snapeda.com/api/url_track_click/https%253A//uk.rs-online.com/web/p/translator-ics/7099038p//%253Futm_campaign%253Dbuynow%2526utm_medium%253Daggreg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 Instruments&part_name=TXB0108PWR&search_term=txb0108 | https://www.snapeda.com/api/url_track_click/https%253A//uk.rs-online.com/web/p/translator-ics/7099038//%253Futm_campaign%253Dbuynow%2526utm_medium%253Daggrega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 Instruments&part_name=TXB0108PWR&search_term=txb0108 |  |  | https://www.snapeda.com/api/url_track_click/https%253A//uk.rs-online.com/web/p/translator-ics/9215119//%253Futm_campaign%253Dbuynow%2526utm_medium%253Daggrega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 Instruments&part_name=TXB0108PWR&search_term=txb0108 | https://www.snapeda.com/parts/TXB0108PWR/Texas+Instruments/view-part/?ref=snap
U4 | MIC5239S | MIC5239S | SOT223 | LDO REGULATOR
X1 | S2B-PH-K-S | S2B-PH-K-S | S2B-PH-K-S | JST PH series header 2.00mm pitch disconnectable crimp style connectors, horizontal (side entry type), 2 pins
X2 | B2B-PH-K-S | B2B-PH-K-S | B2B-PH-K-S | JST PH series header 2.00mm pitch disconnectable crimp style connectors, vertical (side entry type), 2 pins

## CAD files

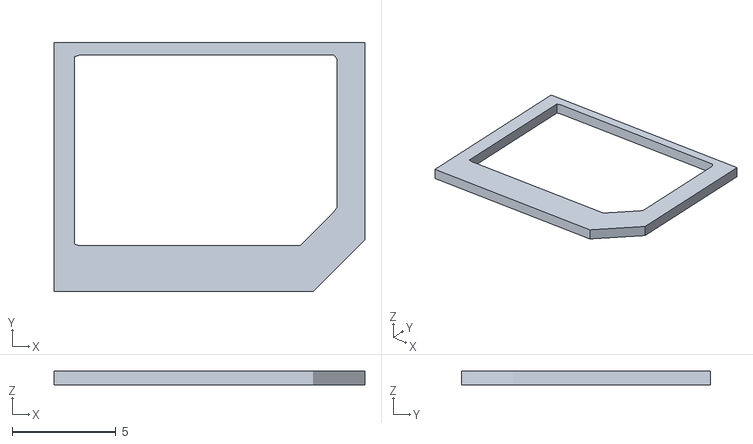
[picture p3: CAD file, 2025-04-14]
Partie_Electronique/Nano to micro sim card adapter 3d/files/04_nano2microSim.stl
15.0 x 12.0 x 0.67

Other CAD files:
Partie_Electronique/Nano to micro sim card adapter 3d/files/04_nano2microSim.scad

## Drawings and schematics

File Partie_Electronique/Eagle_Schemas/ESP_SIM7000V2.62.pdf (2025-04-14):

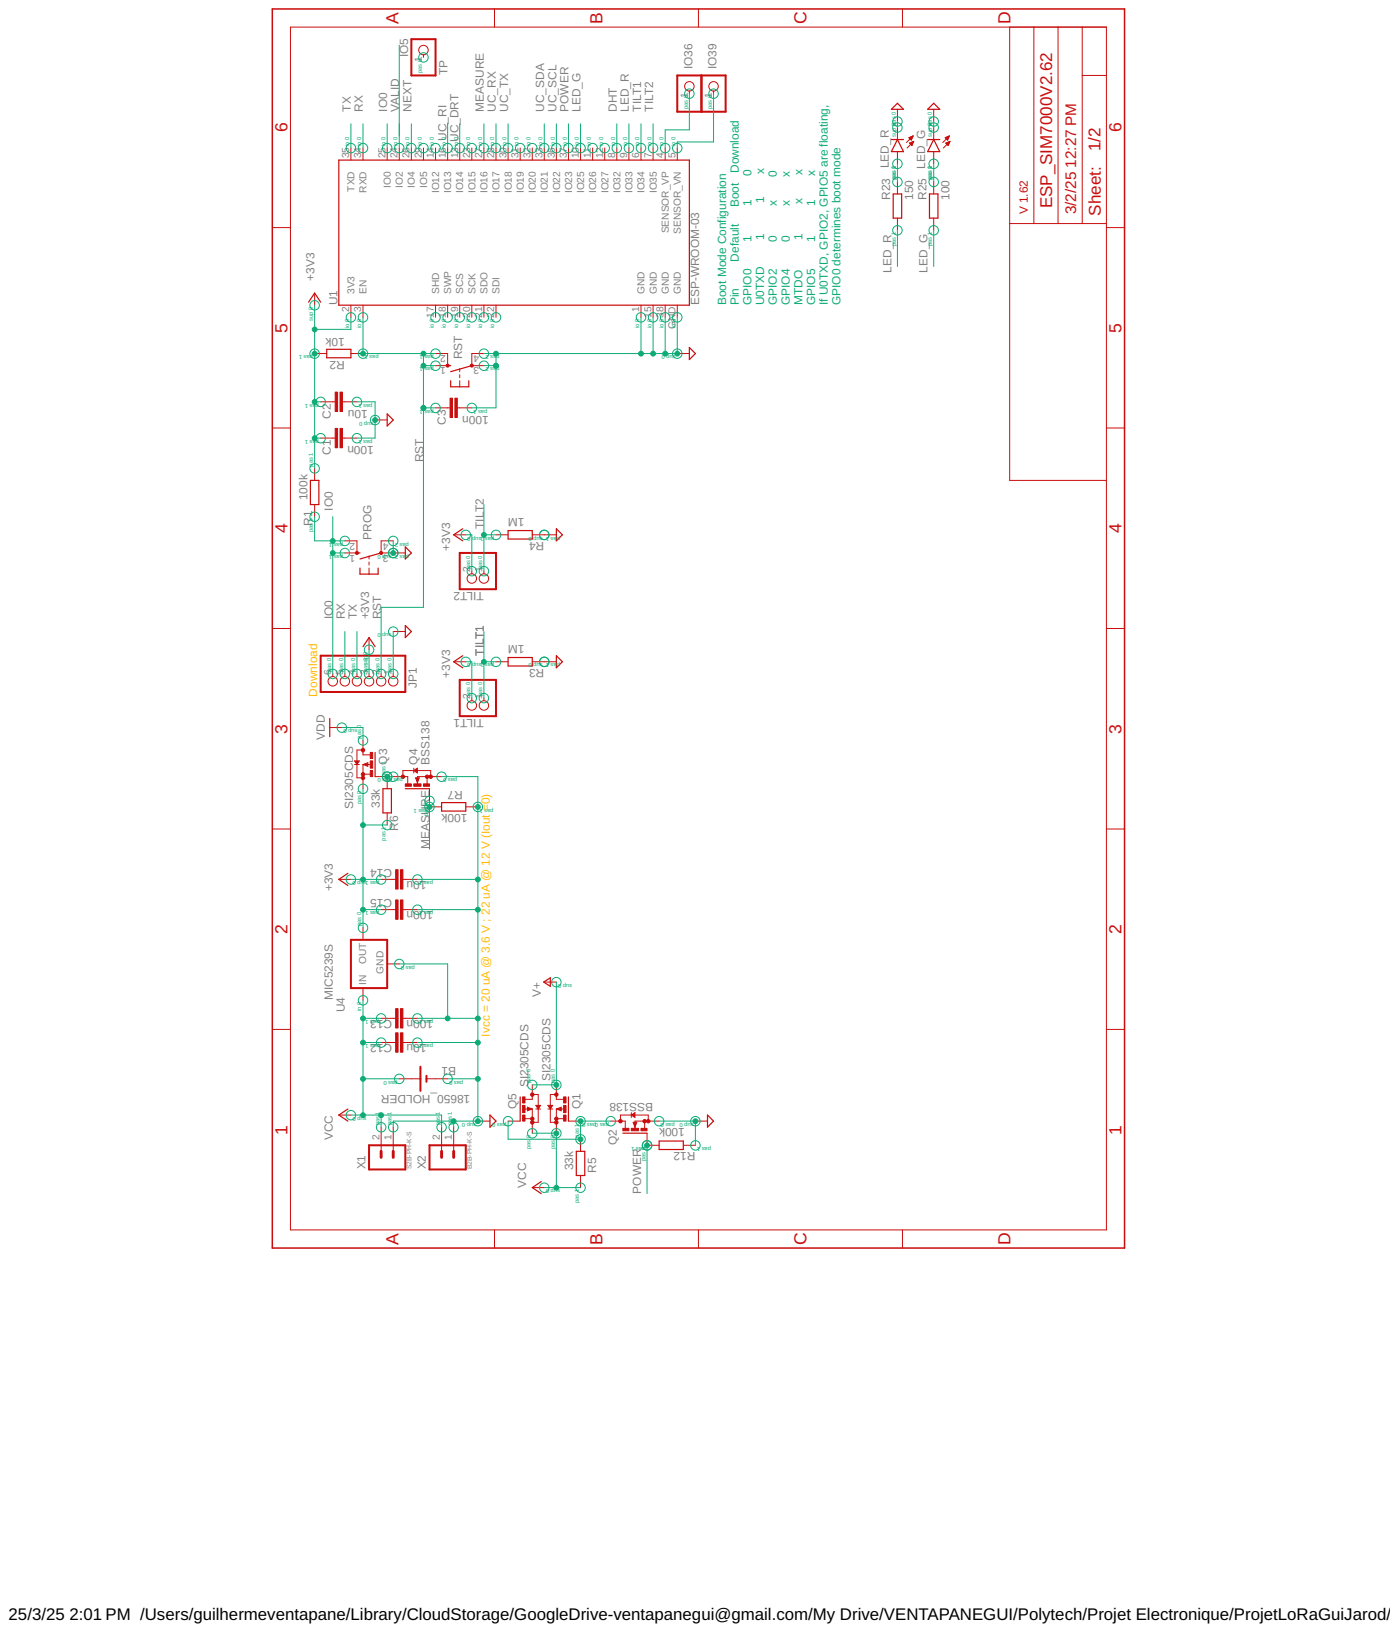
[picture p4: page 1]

TX RX RX RST RST

If U0TXD, GPIO2, GPIO5 are floating, GPIO0 determines boot mode

Boot Mode Configuration Pin Default Boot Download GPIO0 1 1 0 U0TXD 1 1 x GPIO2 0 x 0 GPIO4 0 x x MTDO 1 x x GPIO5 1 1 x

25/3/25 2:01 PM /Users/guilhermeventapane/Library/CloudStorage/GoogleDrive-ventapanegui@gmail.com/My Drive/VENTAPANEGUI/Polytech/Projet Electronique/ProjetLoRaGuiJarod/Lora-GSM-geteway/Schemas/ESP_SIM7000V2.62.sch (Sheet: 1/2)

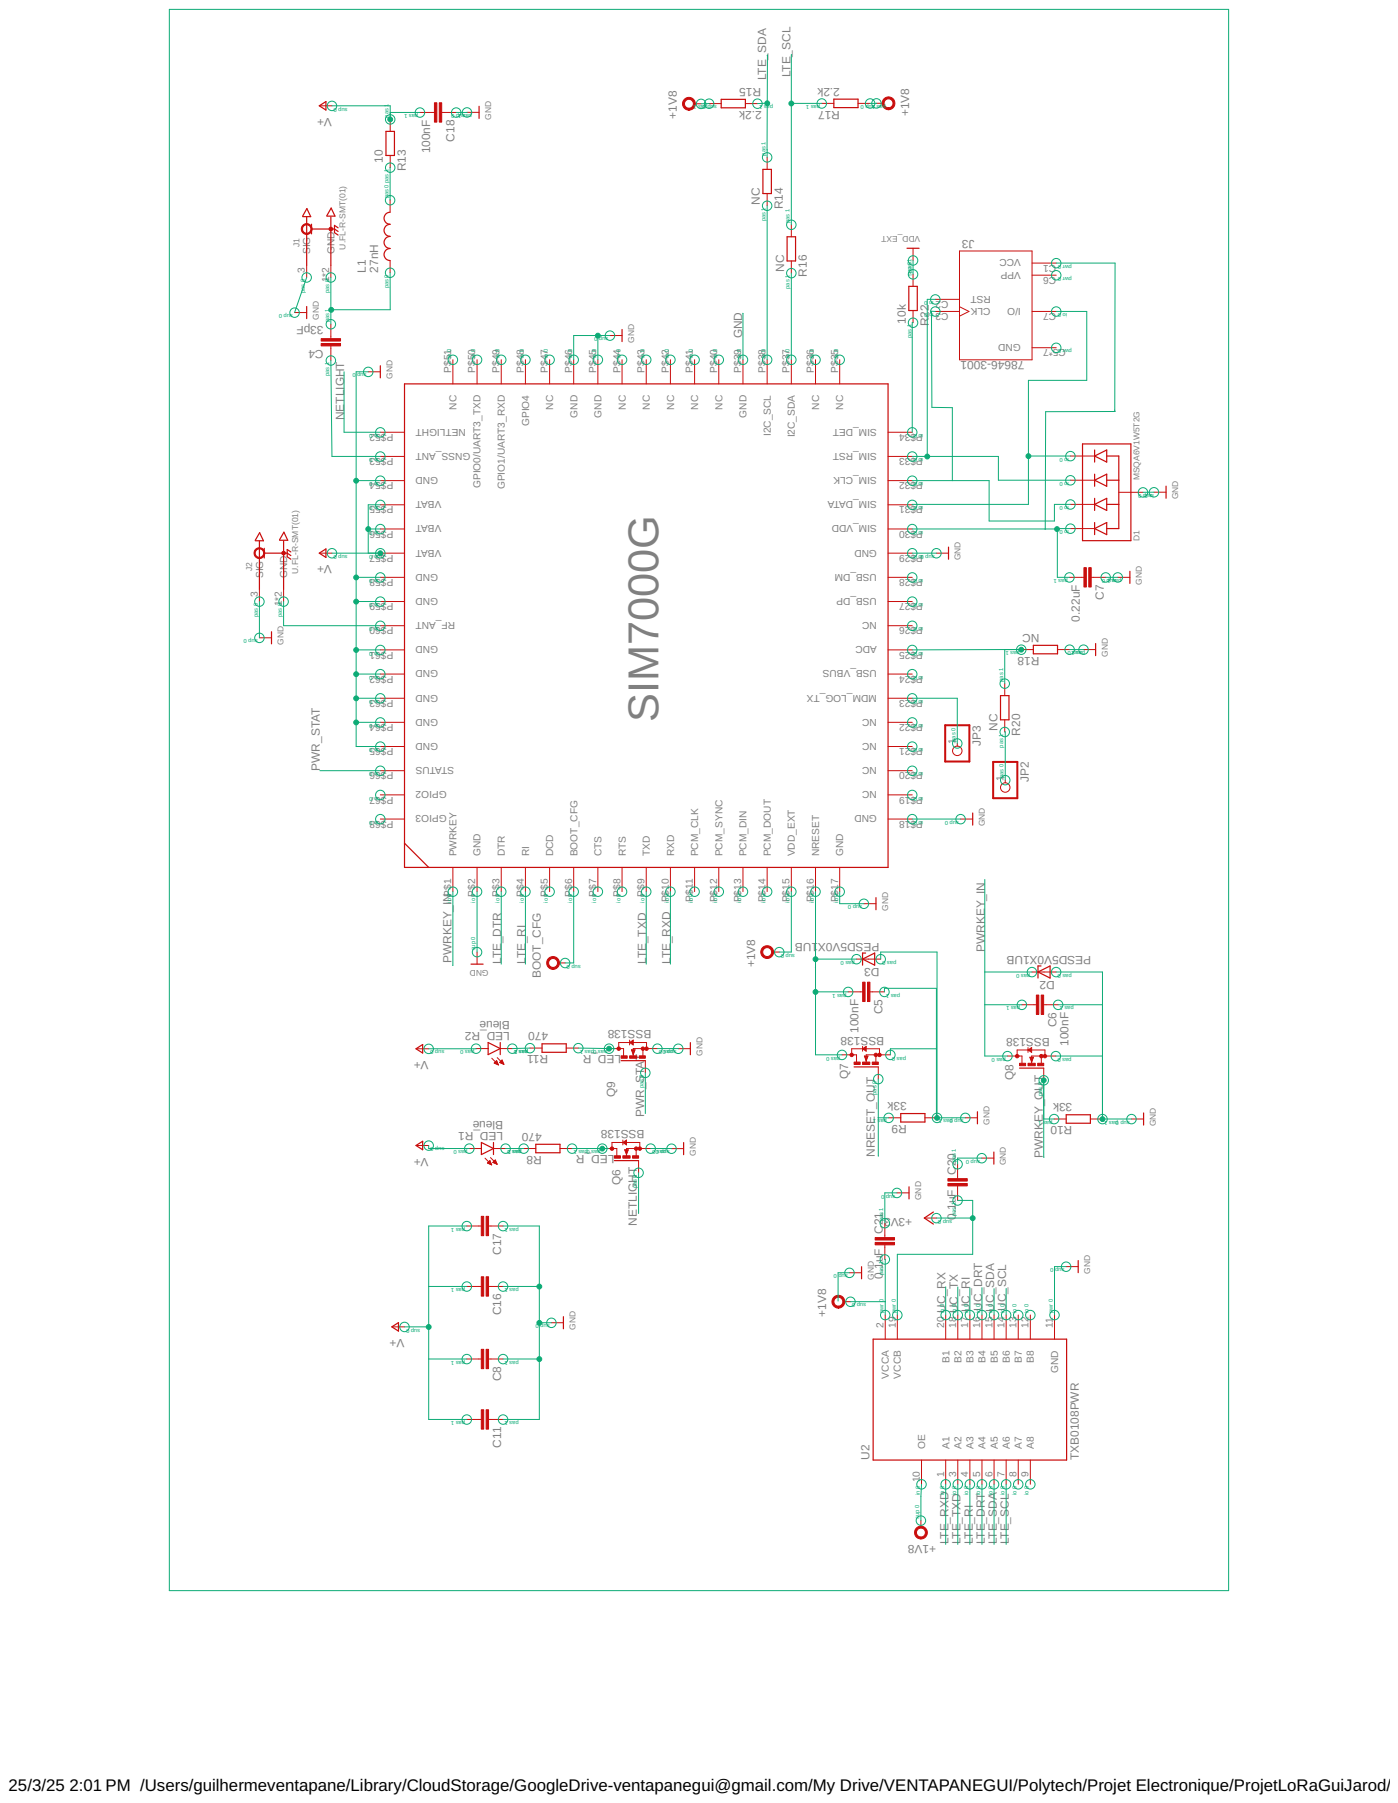
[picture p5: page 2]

U.FL-R-SMT(01) U.FL-R-SMT(01) GND

25/3/25 2:01 PM /Users/guilhermeventapane/Library/CloudStorage/GoogleDrive-ventapanegui@gmail.com/My Drive/VENTAPANEGUI/Polytech/Projet Electronique/ProjetLoRaGuiJarod/Lora-GSM-geteway/Schemas/ESP_SIM7000V2.62.sch (Sheet: 2/2)

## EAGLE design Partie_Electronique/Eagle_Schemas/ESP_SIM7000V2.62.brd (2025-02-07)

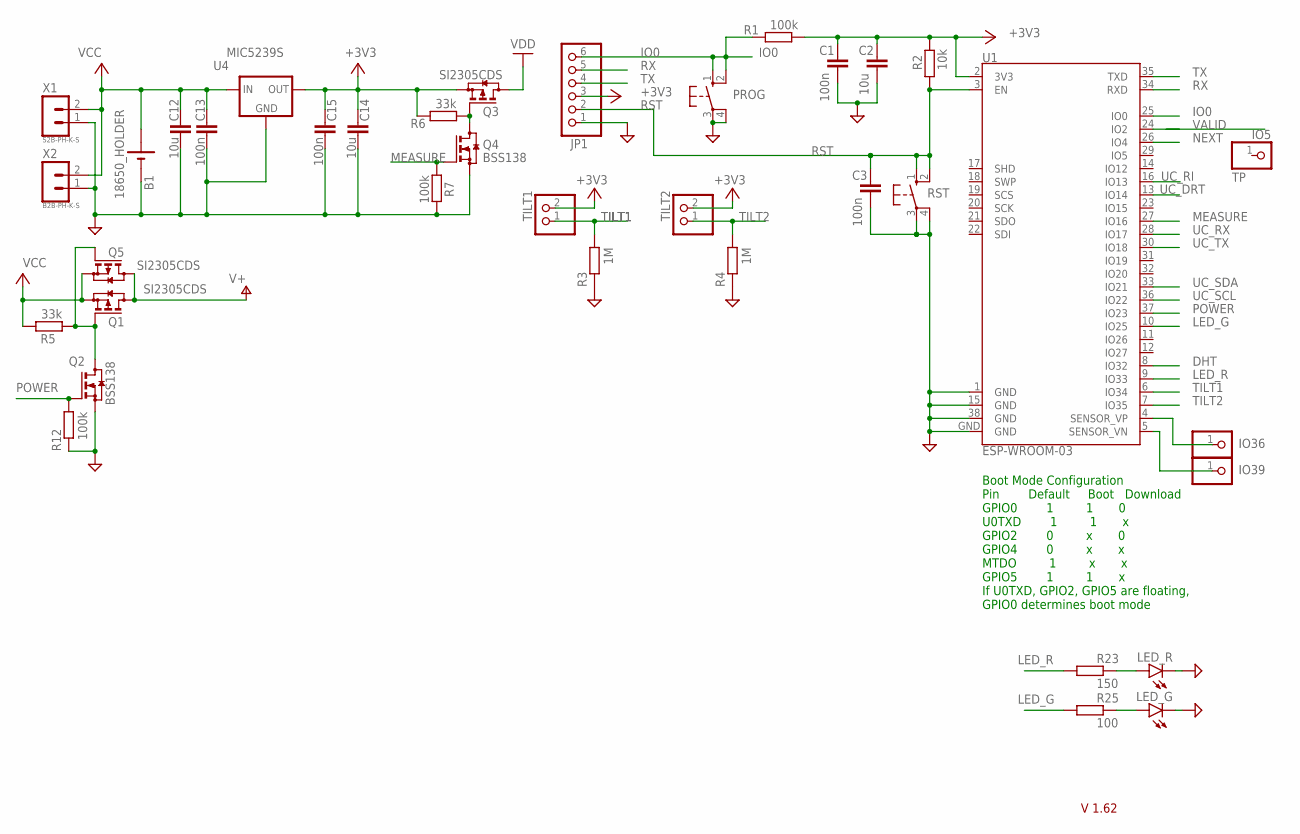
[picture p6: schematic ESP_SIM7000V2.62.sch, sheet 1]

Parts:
B1: 18650_HOLDER; 18650
C1, C3, C13, C15: 100n; C1206
C2, C12, C14: 10u; C1210
IO5: TP; 1X01
IO36, IO39: PINHD-1X1; 1X01
JP1: PINHD-1X6; 1X06
LED_G: LEDSMT1206; 1206
LED_R: LEDSMT1206; 1206
PROG: 10-XX; B3F-10XX
Q1, Q3, Q5: SI2305CDS; SOT23
Q2, Q4: BSS138; SOT23
R1, R7, R12: 100k; R1206
R2: 10k; R1206
R3, R4: 1M; R1206
R5, R6: 33k; R1206
R23: 150; R1206
R25: 100; R1206
RST: 10-XX; B3F-10XX
TILT1, TILT2: PINHD-1X2; 1X02
U1: ESP-WROOM-03
U4: MIC5239S; SOT223
X1: S2B-PH-K-S
X2: B2B-PH-K-S

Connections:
+3V3: C1.1, C2.1, C14.1, C15.1, JP1.3, Q3.2 (S), R1.1, R2.2, R6.2, TILT1.2, TILT2.2, U1.2 (3V3), U4.3 (OUT); also elsewhere on the board
DHT: U1.8 (IO32)
GND: B1.-, C1.2, C2.2, C3.2, C12.2, C13.2, C14.2, C15.2, JP1.1, LED_G.C, LED_R.C, PROG.3, PROG.4 (P1), Q2.2 (S), Q4.2 (S), R3.2, R4.2, R7.2, R12.2, RST.3, RST.4 (P1), U1.1 (GND), U1.15 (GND), U1.38 (GND), U1.GND, U4.2 (GND), U4.4 (GND), X1.1, X2.1; also elsewhere on the board
IO0: JP1.6, PROG.1 (S), PROG.2 (S1), R1.2, U1.25 (IO0)
IO36: IO36.1, U1.4 (SENSOR_VP)
IO39: IO39.1, U1.5 (SENSOR_VN)
LED_G: R25.1, U1.10 (IO25)
LED_R: R23.1, U1.9 (IO33); also elsewhere on the board
MEASURE: Q4.1 (G), R7.1, U1.27 (IO16)
unnamed: Q1.1 (G), Q2.3 (D), Q5.1 (G), R5.1
unnamed: Q3.1 (G), Q4.3 (D), R6.1
unnamed: LED_R.A, R23.2
unnamed: LED_G.A, R25.2
unnamed: IO5.1, U1.29 (IO5)
NEXT: U1.26 (IO4)
POWER: Q2.1 (G), R12.1, U1.37 (IO23)
RST: C3.1, JP1.2, R2.1, RST.1 (S), RST.2 (S1), U1.3 (EN)
RX: JP1.5, U1.34 (RXD)
TILT1: R3.1, TILT1.1, U1.6 (IO34)
TILT2: R4.1, TILT2.1, U1.7 (IO35)
TX: JP1.4, U1.35 (TXD)
UC_DRT: U1.13 (IO14); also elsewhere on the board
UC_RI: U1.16 (IO13); also elsewhere on the board
UC_RX: U1.28 (IO17); also elsewhere on the board
UC_SCL: U1.36 (IO22); also elsewhere on the board
UC_SDA: U1.33 (IO21); also elsewhere on the board
UC_TX: U1.30 (IO18); also elsewhere on the board
V+: Q1.3 (D), Q5.3 (D); also elsewhere on the board
VALID: U1.24 (IO2)
VCC: B1.+, C12.1, C13.1, Q1.2 (S), Q5.2 (S), R5.2, U4.1 (IN), X1.2, X2.2
VDD: Q3.3 (D)

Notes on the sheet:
Boot Mode Configuration Pin Default Boot Download GPIO0 1 1 0 U0TXD 1 1 x GPIO2 0 x 0 GPIO4 0 x x MTDO 1 x x GPIO5 1 1 x If U0TXD, GPIO2, GPIO5 are floating, GPIO0 determines boot mode
V 1.62

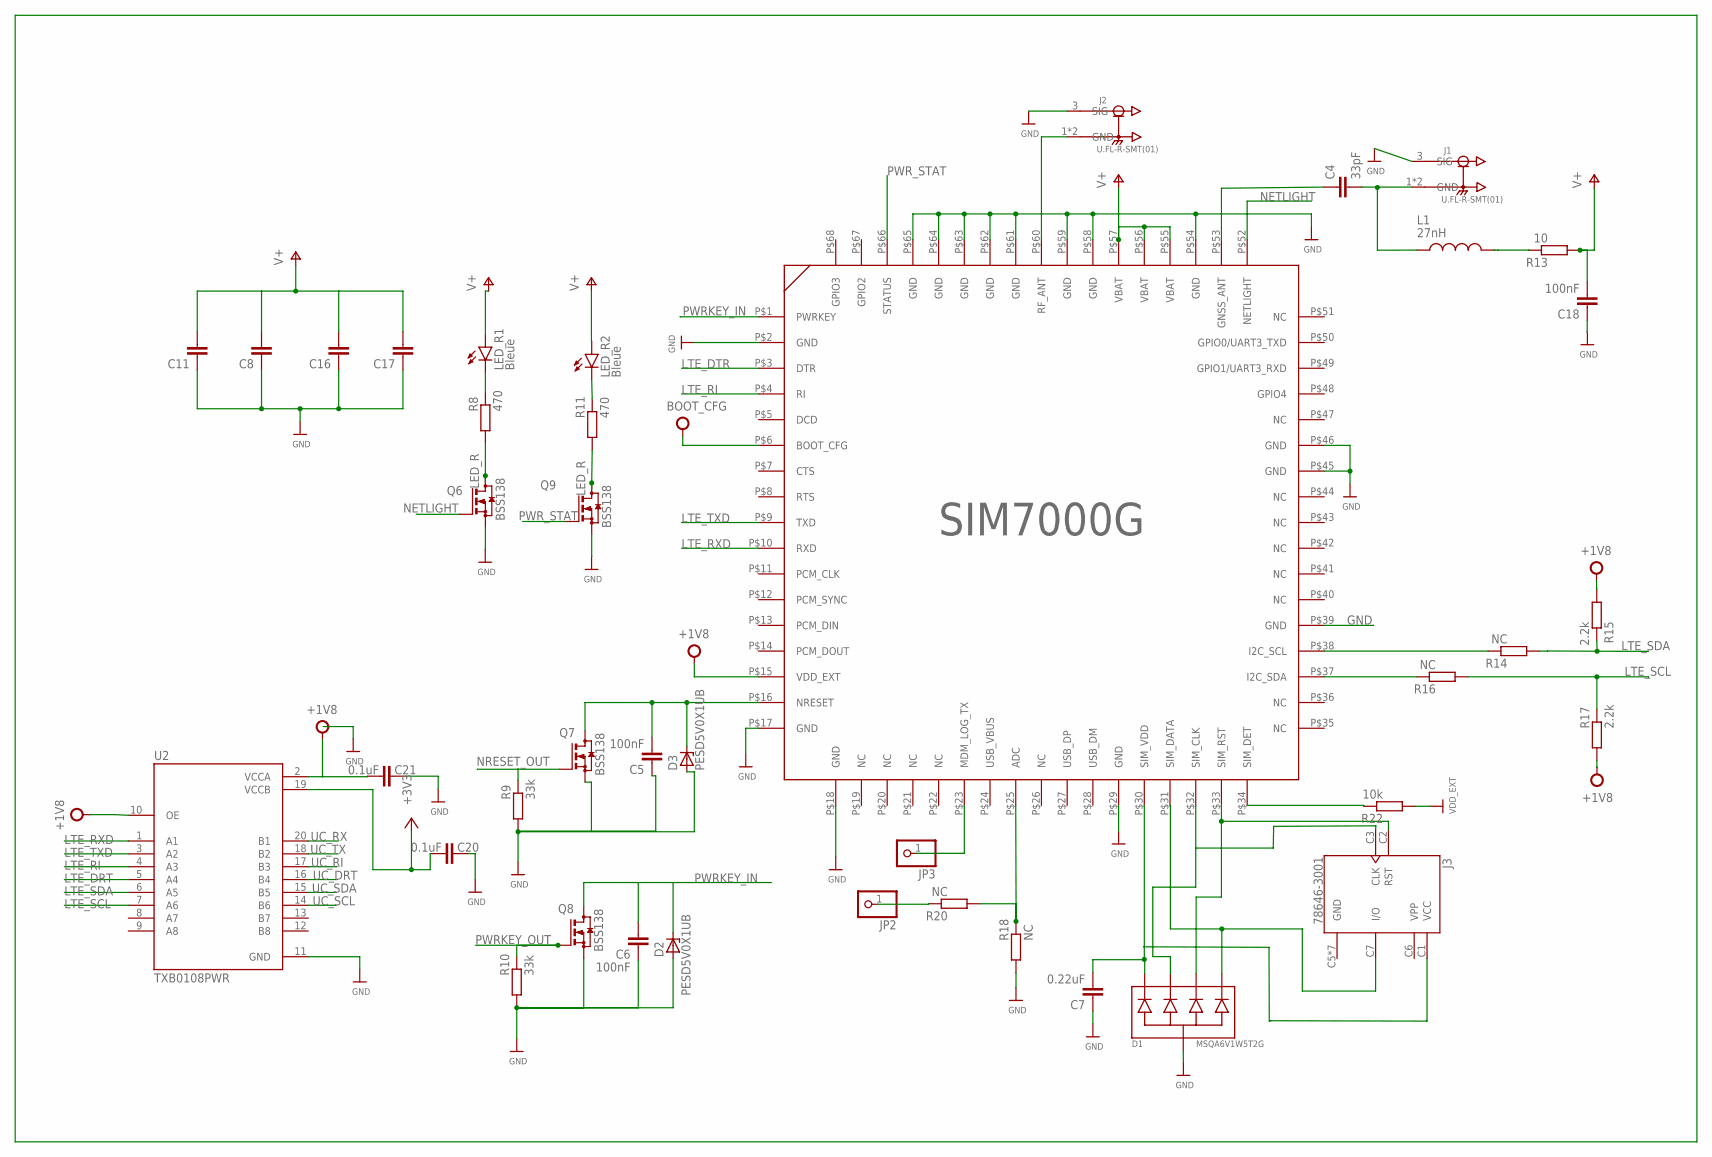
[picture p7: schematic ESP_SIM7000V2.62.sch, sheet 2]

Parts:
C4: 33pF; C0805
C5, C6, C18: 100nF; C0805
C7: 0.22uF; C0805
C8: 1uF; C0805
C11: 0.1uF; C0805
C16, C17: 100uF; C0805
C20, C21: 0.1uF; C1210
D1: MSQA6V1W5T2G; SC88A
D2, D3: PESD5V0X1UB; SOD523
J1, J2: U.FL-R-SMT(01); HRS_U.FL-R-SMT(01)
J3: 78646-3001; MOLEX_78646-3001
JP2, JP3: PINHD-1X1; 1X01
L1: 27nH; INDC2012X100N
LED_R1, LED_R2: Bleue; 1206
Q6, Q7, Q8, Q9: BSS138; SOT23
R8, R11: 470; R1206
R9, R10: 33k; R1206
R13: 10; R1206
R14, R16, R18, R20: NC; R1206
R15, R17: 2.2k; R1206
R22: 10k; R1206
U2: TXB0108PWR; SOP65P640X120-20N
U$1: SIM7000G

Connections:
+1V8: C21.2, R15.1, R17.1, U2.2 (VCCA), U2.10 (OE), U$1.P$6 (BOOT_CFG), U$1.P$15 (VDD_EXT)
+3V3: C20.2, U2.19 (VCCB); also elsewhere on the board
GND: C5.1, C6.1, C7.1, C8.1, C11.1, C16.1, C17.1, C18.1, C20.1, C21.1, D1.2, D2.2 (A), D3.2 (A), J1.3 (SIG), J2.3 (SIG), J3.C5 (GND), J3.G1 (GND), J3.G2 (GND), J3.G3 (GND), J3.G4 (GND), J3.G5 (GND), J3.G6 (GND), Q6.2 (S), Q7.2 (S), Q8.2 (S), Q9.2 (S), R9.1, R10.1, R18.1, R22.1, U2.11 (GND), U$1.P$2 (GND), U$1.P$17 (GND), U$1.P$18 (GND), U$1.P$29 (GND), U$1.P$39 (GND), U$1.P$45 (GND), U$1.P$46 (GND), U$1.P$54 (GND), U$1.P$58 (GND), U$1.P$59 (GND), U$1.P$61 (GND), U$1.P$62 (GND), U$1.P$63 (GND), U$1.P$64 (GND), U$1.P$65 (GND); also elsewhere on the board
LED_R: Q6.3 (D), Q9.3 (D), R8.1, R11.1; also elsewhere on the board
LTE_DRT: U2.5 (A4)
LTE_DTR: U$1.P$3 (DTR)
LTE_RI: U2.4 (A3), U$1.P$4 (RI)
LTE_RXD: U2.1 (A1), U$1.P$10 (RXD)
LTE_SCL: R16.1, R17.2, U2.7 (A6)
LTE_SDA: R14.1, R15.2, U2.6 (A5)
LTE_TXD: U2.3 (A2), U$1.P$9 (TXD)
unnamed: J2.1 (GND), J2.2 (GND), U$1.P$60 (RF_ANT)
unnamed: C4.2, J1.1 (GND), J1.2 (GND), L1.1
unnamed: C4.1, U$1.P$53 (GNSS_ANT)
unnamed: C5.2, D3.1 (K), Q7.3 (D), U$1.P$16 (NRESET)
unnamed: LED_R1.C, R8.2
unnamed: D1.5, J3.C7 (I/O), U$1.P$31 (SIM_DATA)
unnamed: D1.4, J3.C2 (RST), U$1.P$33 (SIM_RST)
unnamed: JP2.1, R20.2
unnamed: LED_R2.C, R11.2
unnamed: R22.2, U$1.P$34 (SIM_DET)
unnamed: L1.2, R13.2
unnamed: D1.3, U$1.P$32 (SIM_CLK)
unnamed: R14.2, U$1.P$38 (I2C_SCL)
unnamed: R16.2, U$1.P$37 (I2C_SDA)
unnamed: C7.2, D1.1, U$1.P$30 (SIM_VDD)
unnamed: R18.2, R20.1, U$1.P$25 (ADC)
unnamed: JP3.1, U$1.P$23 (MDM_LOG_TX)
NETLIGHT: Q6.1 (G), U$1.P$52 (NETLIGHT)
NRESET_OUT: Q7.1 (G), R9.2
PWRKEY_IN: C6.2, D2.1 (K), Q8.3 (D), U$1.P$1 (PWRKEY)
PWRKEY_OUT: Q8.1 (G), R10.2
PWR_STAT: Q9.1 (G), U$1.P$66 (STATUS)
UC_DRT: U2.16 (B4); also elsewhere on the board
UC_RI: U2.17 (B3); also elsewhere on the board
UC_RX: U2.20 (B1); also elsewhere on the board
UC_SCL: U2.14 (B6); also elsewhere on the board
UC_SDA: U2.15 (B5); also elsewhere on the board
UC_TX: U2.18 (B2); also elsewhere on the board
V+: C8.2, C11.2, C16.2, C17.2, C18.2, LED_R1.A, LED_R2.A, R13.1, U$1.P$55 (VBAT), U$1.P$56 (VBAT), U$1.P$57 (VBAT); also elsewhere on the board
VPP: J3.C6 (VPP)

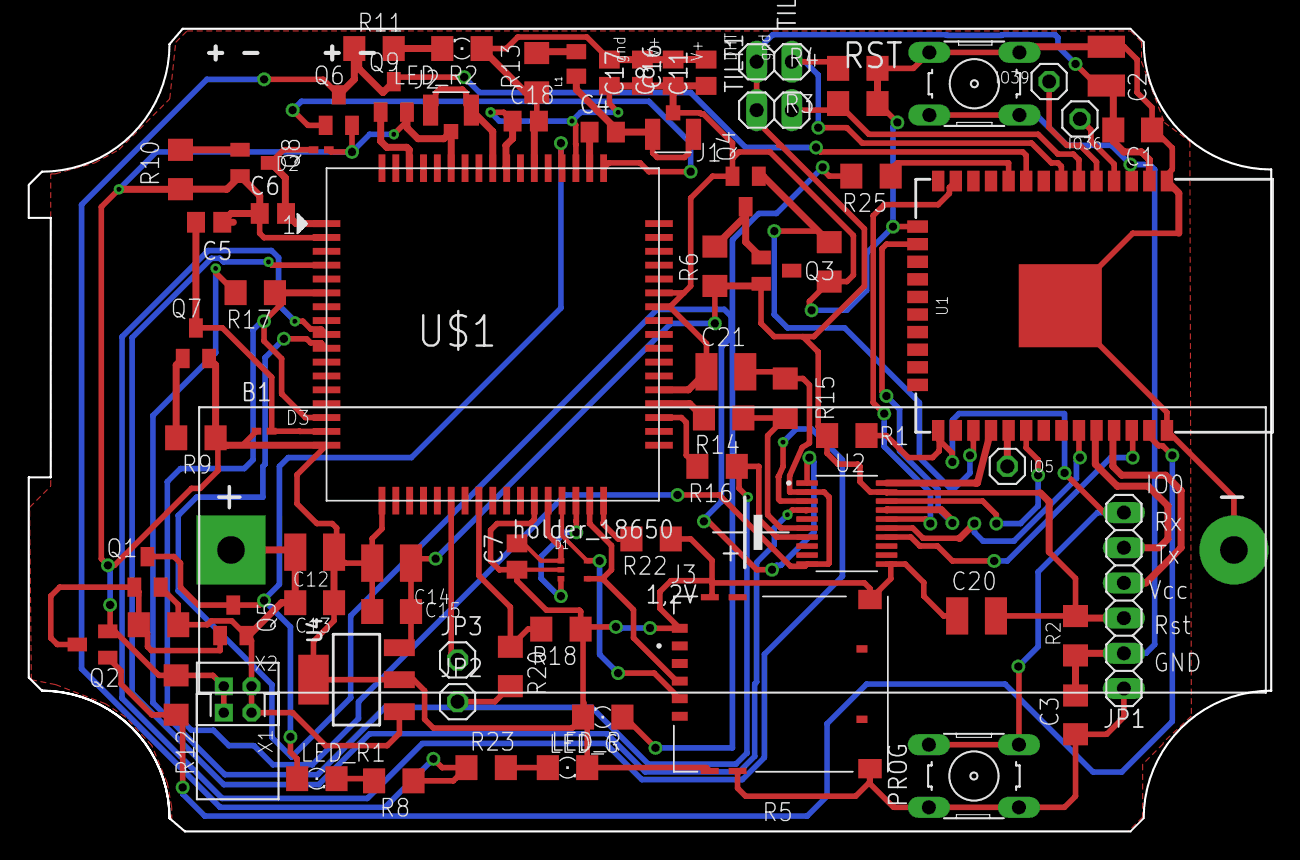
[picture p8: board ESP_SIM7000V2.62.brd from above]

Board: 2 copper layers, 89.7 x 57.9 mm, 77 parts (0 on the bottom side), 55 nets.

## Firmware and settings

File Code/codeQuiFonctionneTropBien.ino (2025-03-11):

/*
  Rui Santos
  Complete project details at https://RandomNerdTutorials.com/lilygo-t-sim7000g-esp32-lte-gprs-gps/
  
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
  The above copyright notice and this permission notice shall be included in all
  copies or substantial portions of the Software.
*/

// Based on the following example: https://github.com/Xinyuan-LilyGO/LilyGO-T-SIM7000G/blob/master/examples/Arduino_TinyGSM/AllFunctions/AllFunctions.ino

#define TINY_GSM_MODEM_SIM7000
#define TINY_GSM_RX_BUFFER 1024 // Set RX buffer to 1Kb
#define SerialAT Serial1

// See all AT commands, if wanted
#define DUMP_AT_COMMANDS

// set GSM PIN, if any
#define GSM_PIN ""

// Your GPRS credentials, if any
const char apn[]  = "sl2sfr";     //SET TO YOUR APN
const char gprsUser[] = "";
const char gprsPass[] = "";

// Set phone number, if you want to test SMS
// Set a recipient phone number to test sending SMS (it must be in international format including the "+" sign)
#define SMS_TARGET  "+33645218132"

#include <TinyGsmClient.h>
#include <SPI.h>
#include <SD.h>
#include <Ticker.h>

#ifdef DUMP_AT_COMMANDS  // if enabled it requires the streamDebugger lib
  #include <StreamDebugger.h>
  StreamDebugger debugger(SerialAT, Serial);
  TinyGsm modem(debugger);
#else
  TinyGsm modem(SerialAT);
#endif

#define uS_TO_S_FACTOR 1000000ULL  // Conversion factor for micro seconds to seconds
#define TIME_TO_SLEEP  60          // Time ESP32 will go to sleep (in seconds)

#define UART_BAUD   115200
#define PIN_DTR     25
#define PIN_TX      20
#define PIN_RX      19
#define PWR_PIN     4

#define SD_MISO     2
#define SD_MOSI     15
#define SD_SCLK     14
#define SD_CS       13
#define LED_PIN     12

int counter, lastIndex, numberOfPieces = 24;
String pieces[24], input;

void setup(){
  // Set console baud rate
  Serial.begin(115200);
  delay(10);

  // Set LED OFF
  pinMode(LED_PIN, OUTPUT);
  digitalWrite(LED_PIN, HIGH);

  pinMode(PWR_PIN, OUTPUT);
  digitalWrite(PWR_PIN, HIGH);
  delay(300);
  digitalWrite(PWR_PIN, LOW);

  SPI.begin(SD_SCLK, SD_MISO, SD_MOSI, SD_CS);
  if (!SD.begin(SD_CS)) {
    Serial.println("SDCard MOUNT FAIL");
  } else {
    uint32_t cardSize = SD.cardSize() / (1024 * 1024);
    String str = "SDCard Size: " + String(cardSize) + "MB";
    Serial.println(str);
  }

  Serial.println("\nWait...");

  delay(1000);

  SerialAT.begin(UART_BAUD, SERIAL_8N1, PIN_RX, PIN_TX);

  // Restart takes quite some time
  // To skip it, call init() instead of restart()
  Serial.println("Initializing modem...");
  if (!modem.restart()) {
    Serial.println("Failed to restart modem, attempting to continue without restarting");
  }
}

void loop(){
  // Restart takes quite some time
  // To skip it, call init() instead of restart()
  Serial.println("Initializing modem...");
  if (!modem.init()) {
    Serial.println("Failed to restart modem, attempting to continue without restarting");
  }

  String name = modem.getModemName();
  delay(500);
  Serial.println("Modem Name: " + name);

  String modemInfo = modem.getModemInfo();
  delay(500);
  Serial.println("Modem Info: " + modemInfo);
  

  // Unlock your SIM card with a PIN if needed
  if ( GSM_PIN && modem.getSimStatus() != 3 ) {
      modem.simUnlock(GSM_PIN);
  }
  modem.sendAT("+CFUN=0 ");
  if (modem.waitResponse(10000L) != 1) {
    DBG(" +CFUN=0  false ");
  }
  delay(200);

  /*
    2 Automatic
    13 GSM only
    38 LTE only
    51 GSM and LTE only
  * * * */
  String res;
  // CHANGE NETWORK MODE, IF NEEDED
  res = modem.setNetworkMode(2);
  if (res != "1") {
    DBG("setNetworkMode  false ");
    return ;
  }
  delay(200);

  /*
    1 CAT-M
    2 NB-Iot
    3 CAT-M and NB-IoT
  * * */
  // CHANGE PREFERRED MODE, IF NEEDED
  res = modem.setPreferredMode(1);
  if (res != "1") {
    DBG("setPreferredMode  false ");
    return ;
  }
  delay(200);

  /*AT+CBANDCFG=<mode>,<band>[,<band>…]
   * <mode> "CAT-M"   "NB-IOT"
   * <band>  The value of <band> must is in the band list of getting from  AT+CBANDCFG=?
   * For example, my SIM card carrier "NB-iot" supports B8.  I will configure +CBANDCFG= "Nb-iot ",8
   */
  /* modem.sendAT("+CBANDCFG=\"NB-IOT\",8 ");*/
  
  /* if (modem.waitResponse(10000L) != 1) {
       DBG(" +CBANDCFG=\"NB-IOT\" ");
   }*/
   delay(200);

  modem.sendAT("+CFUN=1 ");
  if (modem.waitResponse(10000L) != 1) {
    DBG(" +CFUN=1  false ");
  }
  delay(200);

  SerialAT.println("AT+CGDCONT?");
  delay(500);
  if (SerialAT.available()) {
    input = SerialAT.readString();
    for (int i = 0; i < input.length(); i++) {
      if (input.substring(i, i + 1) == "\n") {
        pieces[counter] = input.substring(lastIndex, i);
        lastIndex = i + 1;
        counter++;
       }
        if (i == input.length() - 1) {
          pieces[counter] = input.substring(lastIndex, i);
        }
      }
      // Reset for reuse
      input = "";
      counter = 0;
      lastIndex = 0;

      for ( int y = 0; y < numberOfPieces; y++) {
        for ( int x = 0; x < pieces[y].length(); x++) {
          char c = pieces[y][x];  //gets one byte from buffer
          if (c == ',') {
            if (input.indexOf(": ") >= 0) {
              String data = input.substring((input.indexOf(": ") + 1));
              if ( data.toInt() > 0 && data.toInt() < 25) {
                modem.sendAT("+CGDCONT=" + String(data.toInt()) + ",\"IP\",\"" + String(apn) + "\",\"0.0.0.0\",0,0,0,0");
              }
              input = "";
              break;
            }
          // Reset for reuse
          input = "";
         } else {
          input += c;
         }
      }
    }
  } else {
    Serial.println("Failed to get PDP!");
  }

  Serial.println("\n\n\nWaiting for network...");
  if (!modem.waitForNetwork()) {
    delay(10000);
    return;
  }

  if (modem.isNetworkConnected()) {
    Serial.println("Network connected");
  }
  
  // --------TESTING GPRS--------
  Serial.println("\n---Starting GPRS TEST---\n");
  Serial.println("Connecting to: " + String(apn));
  if (!modem.gprsConnect(apn, gprsUser, gprsPass)) {
    delay(10000);
    return;
  }

  Serial.print("GPRS status: ");
  if (modem.isGprsConnected()) {
    Serial.println("connected");
  } else {
    Serial.println("not connected");
  }

  String ccid = modem.getSimCCID();
  Serial.println("CCID: " + ccid);

  String imei = modem.getIMEI();
  Serial.println("IMEI: " + imei);

  String cop = modem.getOperator();
  Serial.println("Operator: " + cop);

  IPAddress local = modem.localIP();
  Serial.println("Local IP: " + String(local));

  int csq = modem.getSignalQuality();
  Serial.println("Signal quality: " + String(csq));

  SerialAT.println("AT+CPSI?");     //Get connection type and band
  delay(500);
  if (SerialAT.available()) {
    String r = SerialAT.readString();
    Serial.println(r);
  }

  Serial.println("\n---End of GPRS TEST---\n");

  modem.gprsDisconnect();
  if (!modem.isGprsConnected()) {
    Serial.println("GPRS disconnected");
  } else {
    Serial.println("GPRS disconnect: Failed.");
  }

  // --------TESTING GPS--------
  /*
  Serial.println("\n---Starting GPS TEST---\n");
  // Set SIM7000G GPIO4 HIGH ,turn on GPS power
  // CMD:AT+SGPIO=0,4,1,1
  // Only in version 20200415 is there a function to control GPS power
  modem.sendAT("+SGPIO=0,4,1,1");
  if (modem.waitResponse(10000L) != 1) {
    DBG(" SGPIO=0,4,1,1 false ");
  }
  modem.enableGPS();
  float lat,  lon;
  while (1) {
    if (modem.getGPS(&lat, &lon)) {
      Serial.printf("lat:%f lon:%f\n", lat, lon);
      break;
    } else {
      Serial.print("getGPS ");
      Serial.println(millis());
    }
    delay(2000);
  }
  modem.disableGPS();

  // Set SIM7000G GPIO4 LOW ,turn off GPS power
  // CMD:AT+SGPIO=0,4,1,0
  // Only in version 20200415 is there a function to control GPS power
  modem.sendAT("+SGPIO=0,4,1,0");
  if (modem.waitResponse(10000L) != 1) {
    DBG(" SGPIO=0,4,1,0 false ");
  }
  Serial.println("\n---End of GPRS TEST---\n");
*/

  // --------TESTING SENDING SMS--------
  res = modem.sendSMS(SMS_TARGET, String("Hello from ") + imei);
  DBG("SMS:", res ? "Envoyé" : "fail");

  res = modem.sendSMS(SMS_TARGET, String("Hello from ") + imei);
  DBG("SMS:", res ? "Envoyé" : "fail");


  // --------TESTING POWER DONW--------

  // Try to power-off (modem may decide to restart automatically)
  // To turn off modem completely, please use Reset/Enable pins
  modem.sendAT("+CPOWD=1");
  if (modem.waitResponse(10000L) != 1) {
    DBG("+CPOWD=1");
  }
  // The following command does the same as the previous lines
  modem.poweroff();
  Serial.println("Poweroff.");

  // GO TO SLEEP
  esp_sleep_enable_timer_wakeup(TIME_TO_SLEEP * uS_TO_S_FACTOR);
  delay(200);
  esp_deep_sleep_start();

  // Do nothing forevermore
  while (true) {
      modem.maintain();
  }
}

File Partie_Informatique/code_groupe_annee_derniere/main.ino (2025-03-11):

#define TINY_GSM_MODEM_SIM7000

#include "RucherLoRa.h"
#include <TinyGsmClient.h>

// Define RX/TX pins for ESP32 <-> SIM7000G communication
#define MODEM_TX 20  // ESP32 TX → SIM7000 RX
#define MODEM_RX 19  // ESP32 RX → SIM7000 TX
#define PWRKEY    4  // SIM7000 Power Key (adjust if needed)
#define RESET     5  // SIM7000 Reset Pin (optional)

TinyGsm modem(Serial1);

// Function prototypes
void powerOnSIM7000();
void initLTE(const char* apn);
void sendMessage(const char* number, const char* message);
void readMessage();

void setup() {
    Serial.begin(115200);
    delay(3000);
    
    Serial.println("Initializing Serial1 for SIM7000G...");
    Serial1.begin(115200, SERIAL_8N1, MODEM_RX, MODEM_TX);

    // Power on SIM7000G
    powerOnSIM7000();
    delay(5000);

    // Set LTE APN (modify as per your provider)
    const char* apn = "orange";
    initLTE(apn);
    delay(3000);

    // Read incoming messages
    readMessage();

    // Send an SMS
    const char* recipient = "+33635150270"; // Replace with the real number
    const char* message = "Hello from your SIM7000 with RucherLoRa!";
    sendMessage(recipient, message);
}

void loop() {
    // Example: Uncomment if you want to send an SMS periodically
    // sendMessage("+33645218132", "Hello, World!");
    // delay(60000); // Send a message every 60 seconds

    // Example: Read signal strength every 10 seconds
    Serial.println("Checking signal strength...");
    modem.sendAT("AT+CSQ");
    delay(10000);
}

// Function to power on the SIM7000G module
void powerOnSIM7000() {
    pinMode(PWRKEY, OUTPUT);
    digitalWrite(PWRKEY, LOW);
    delay(1000);
    digitalWrite(PWRKEY, HIGH);
    Serial.println("Powering on SIM7000...");
}
/*
// Function to initialize LTE connection
void initLTE(const char* apn) {
    Serial.println("Initializing LTE...");

    // Set APN for network connection
    String cmd = "AT+CGDCONT=1,\"IP\",\"";
    cmd += apn;
    cmd += "\"";
    modem.sendAT(cmd.c_str());
    delay(1000);

    // Ensure module is in LTE mode
    modem.sendAT("AT+CNMP=51"); // LTE-only mode
    delay(1000);

    Serial.println("LTE Initialized!");
}

// Function to send an SMS
void sendMessage(const char* number, const char* message) {
    Serial.print("Sending SMS to ");
    Serial.println(number);
    
    modem.sendAT("AT+CMGF=1");  // Set SMS mode to text
    delay(1000);
    
    String smsCmd = "AT+CMGS=\"";
    smsCmd += number;
    smsCmd += "\"";
    
    modem.sendAT(smsCmd.c_str());
    delay(1000);
    
    modem.stream.print(message);
    delay(500);
    
    modem.stream.write(26); // End SMS with CTRL+Z
    delay(5000);

    Serial.println("SMS Sent!");
}

// Function to read received messages
void readMessage() {
    Serial.println("Checking for incoming messages...");
    modem.sendAT("AT+CMGL=\"REC UNREAD\"");  // Read unread messages
    delay(1000);
}*/

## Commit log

2024-11-25 Rajout de la documentation et des schémas.
    [ESP_SIM7000V2.62.brd, ESP_SIM7000V2.62.sch]
2024-11-25 Fichiers et dossiers
    [ESP_SIM7000V2.62.brd, ESP_SIM7000V2.62.sch]
2024-11-26 Enlevé des fichiers non necessaires
2024-11-26 Update cahier de charges
2024-12-05 Update Guilherme.md avec les images des erreurs.
2024-12-05 Plus de détails sur l'avancement
2024-12-05 Rajouté le l'URL de la formation EAGLE j'ai suivi.
2024-12-05 Correction de mes erreurs de Français
2024-12-05 Rajouté les jours de semaine
2025-01-31 Mouvement, voiture aléatoires, deux types de NPC...
    [ESP_SIM7000V2.62.brd, ESP_SIM7000V2.62.sch]
2025-02-03 Modifs EAGLE et Compte rendu
    [ESP_SIM7000V2.62.brd, ESP_SIM7000V2.62.sch]
2025-02-07 PCB OK
    [ESP_SIM7000V2.62.brd]
2025-02-25 Réussi à faire fonctionner le code pour communiquer l'ESP32 avec la SIM7000G.
2025-02-26 Ajouté le code de l'année dernière pour faire des essais.
2025-02-28 Gitignore de DS_Store
2025-03-11 Fait marcher la carte et envoyer le SMS, voir "codeQuiFonctionneTropBien.ino"
2025-04-11 Add rapport and 3d sim
    [04_nano2microSim.scad, 04_nano2microSim.stl]
2025-04-14 Compte rendu Guilherme
    [ESP_SIM7000V2.62_BOM.csv]
2025-04-14 Déplacé les fichiers de la carte SIM pour mieux organiser les dossiers de notre projet.
    [04_nano2microSim.scad, 04_nano2microSim.stl]
2025-04-14 Déplacé dossiers
    [04_nano2microSim.scad, 04_nano2microSim.stl]
2025-04-14 Réorganisé tous les dossiers du projet.
    [04_nano2microSim.scad, 04_nano2microSim.stl, ESP_SIM7000V2.62.brd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]
2025-05-17 Enlevé la partie du code qui ne sert pas à notre projet

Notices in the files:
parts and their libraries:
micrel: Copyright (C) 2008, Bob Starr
